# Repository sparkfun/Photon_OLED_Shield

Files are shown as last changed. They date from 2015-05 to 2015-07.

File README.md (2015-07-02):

SparkFun Photon OLED Shield
========================================

SparkFun Photon OLED Shield

[*SparkFun Photon OLED Shield (DEV-13628)*](https://www.sparkfun.com/products/13628)

The [SparkFun Photon OLED Shield](https://www.sparkfun.com/products/13231) breaks out a small monochrome, blue-on-black OLED to use with your Photon module. It’s “micro”, but it still packs a punch – the OLED display is crisp, and you can fit a deceivingly large amount of graphics on there. This shield is perfect for adding graphics to your Photon, displaying diagnostic information without resorting to serial output, and teaching a little game theory.

Repository Contents
-------------------

* **/Hardware** - Eagle design files (.brd, .sch)
* **/Production** - Production panel files (.brd)
* **/Libraries** - Firmware library and example code for the Particle Photon.

Documentation
--------------
* **[Hookup Guide](https://learn.sparkfun.com/tutorials/photon-oled-shield-hookup-guide)** - Hardware overview and example code.

Product Versions
----------------
* [DEV-13628](https://www.sparkfun.com/products/13628)- V1.0 release of the Photon OLED Shield.

License Information
-------------------
This product is _**open source**_! 

The **hardware** is released under [Creative Commons ShareAlike 4.0 International](https://creativecommons.org/licenses/by-sa/4.0/).

The **code**  license can be found in the source directory.

Please use, reuse, and modify these files as you see fit. Please maintain attribution to SparkFun Electronics and release anything derivative under the same license.

Distributed as-is; no warranty is given.

- Your friends at SparkFun.

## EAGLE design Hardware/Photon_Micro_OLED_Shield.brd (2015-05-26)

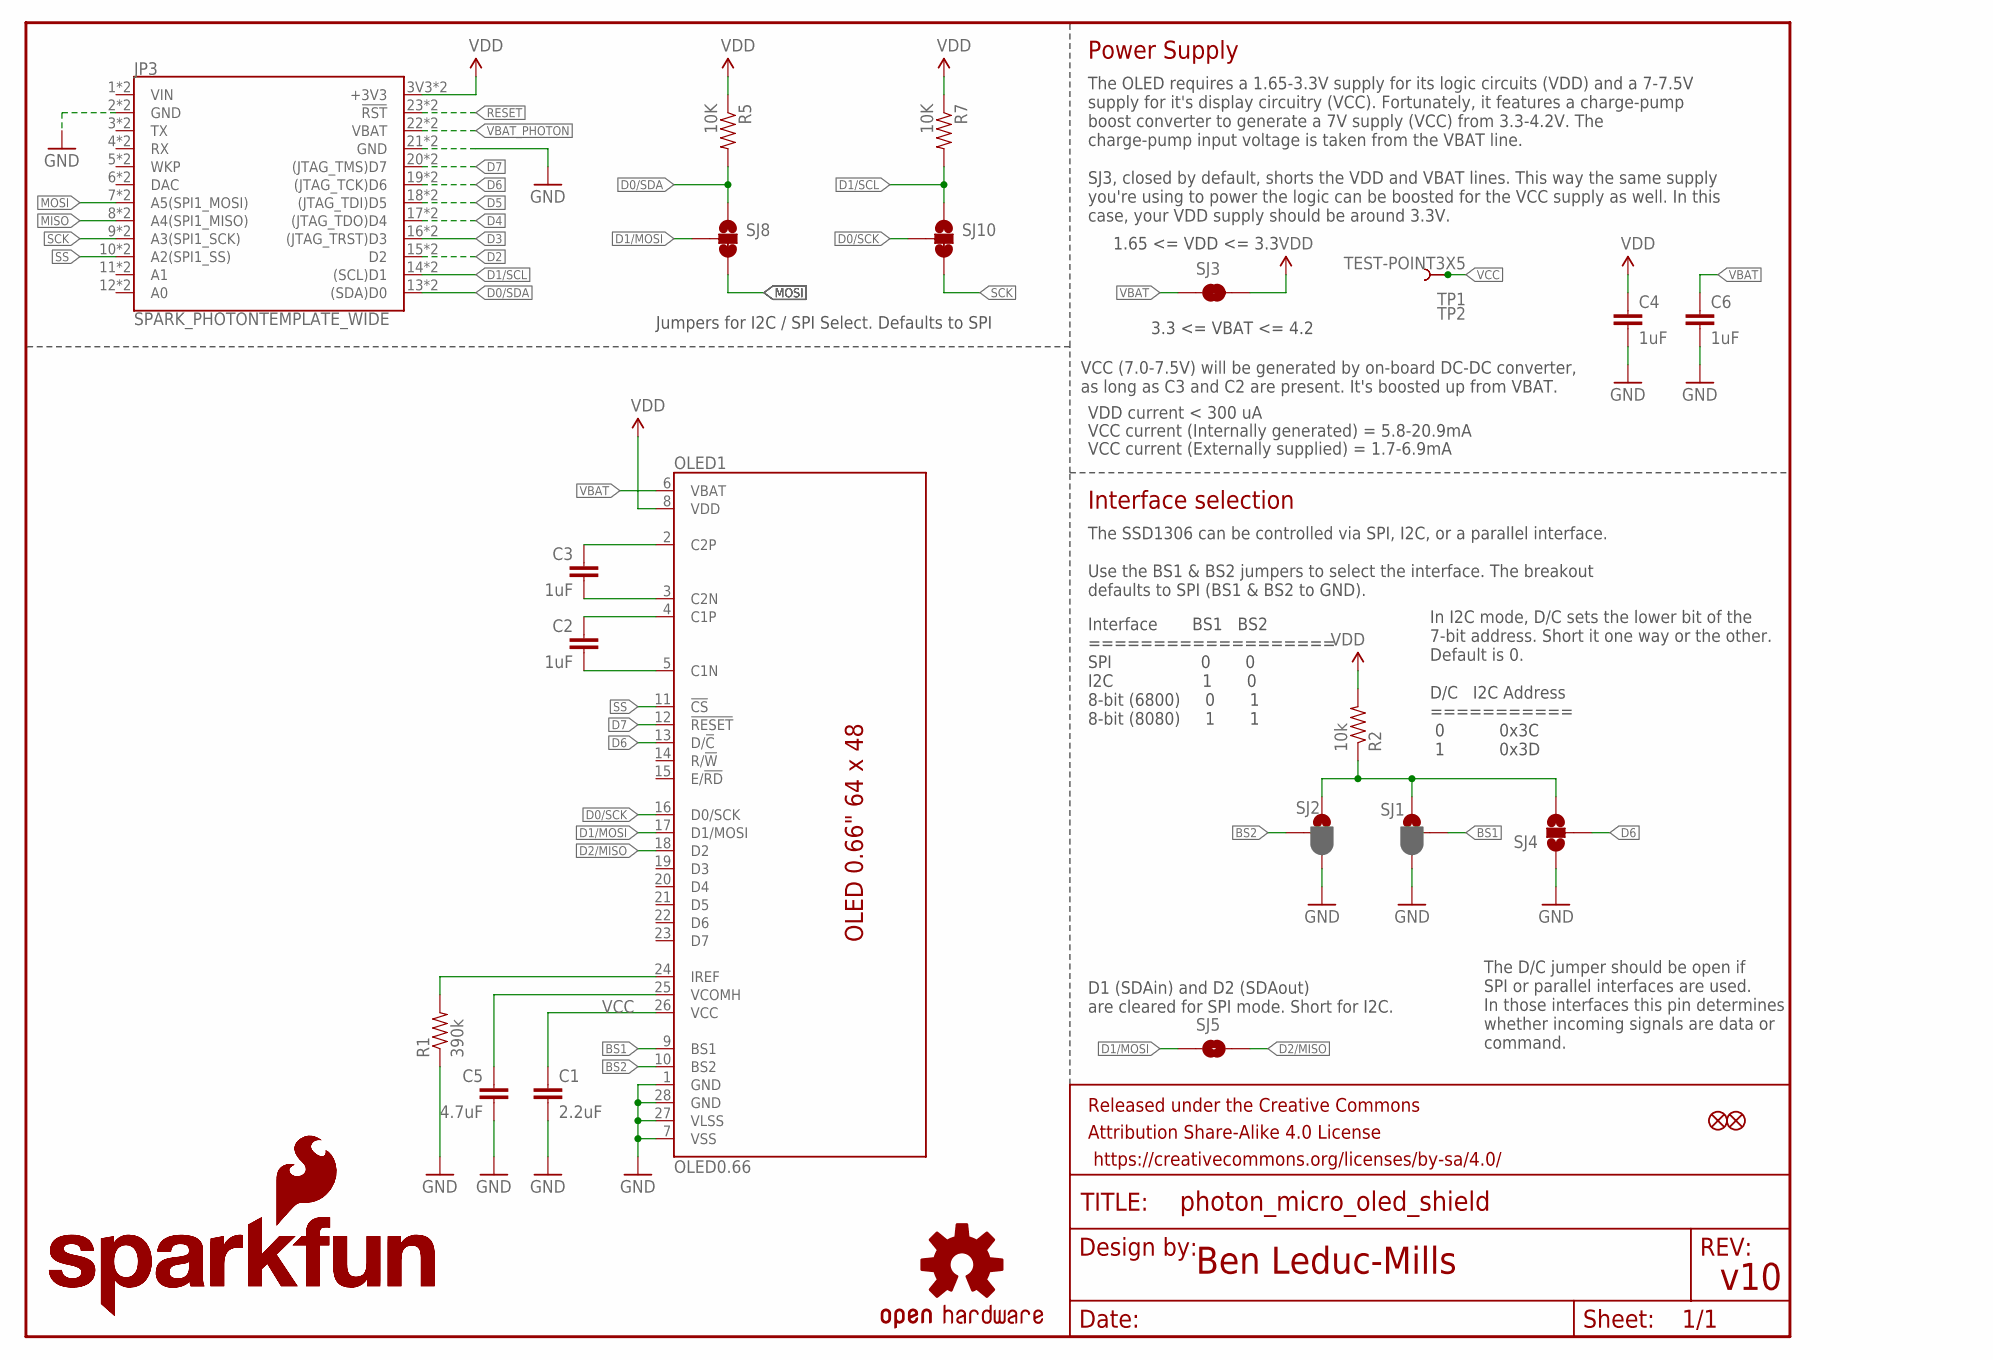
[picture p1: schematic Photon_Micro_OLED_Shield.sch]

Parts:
C1: 2.2uF; 0805-CAP
C2, C3: 1uF; 0805-CAP
C4, C6: 1uF; 0603-CAP
C5: 4.7uF; 1206-CAP
FID1, FID2: FIDUCIAL1X2; FIDUCIAL-1X2
FRAME1: FRAME-LETTER; CREATIVE_COMMONS
JP3: SPARK_PHOTONTEMPLATE_WIDE; SPARK_PHOTON_TEMPLATE_WIDE
LOGO1, LOGO2: SFE_LOGO_NAME_FLAME.1_INCH; SFE_LOGO_NAME_FLAME_.1
LOGO3: OSHW-LOGOS; OSHW-LOGO-S
OLED1: OLED0.66; OLED-0.66-64X48
R1: 390k; 0603-RES
R2: 10k; 0603-RES
R5, R7: 10K; 0603-RES
SJ1: BS1; PAD-JUMPER-3-2OF3_NC_BY_PASTE_YES_SILK_FULL_BOX
SJ2: BS2; PAD-JUMPER-3-2OF3_NC_BY_PASTE_YES_SILK_FULL_BOX
SJ3: JUMPER-PAD-2-NC_BY_TRACE; PAD-JUMPER-2-NC_BY_TRACE_YES_SILK
SJ4: JUMPER-PAD-3-NOYES_SILK; PAD-JUMPER-3-NO_YES_SILK
SJ5: JUMPER-PAD-2-NOYES_SILK; PAD-JUMPER-2-NO_YES_SILK
SJ8, SJ10: JUMPER-PAD-3-2OF3_NC_BY_TRACE_SMALL; PAD-JUMPER-3-2OF3_NC_BY_TRACE_YES_SILK_FULL_BOX
TP1, TP2: TEST-POINT3X5; PAD.03X.05

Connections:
BS1: OLED1.9 (BS1), SJ1.2
BS2: OLED1.10 (BS2), SJ2.2
C1N: C2.2, OLED1.5 (C1N)
C1P: C2.1, OLED1.4 (C1P)
C2N: C3.2, OLED1.3 (C2N)
C2P: C3.1, OLED1.2 (C2P)
D0/SCK: OLED1.16 (D0/SCK), SJ10.2
D0/SDA: JP3.13 ((SDA)D0), JP3.D0 ((SDA)D0), R5.2, SJ8.1
D1/MOSI: OLED1.17 (D1/MOSI), SJ5.1, SJ8.2
D1/SCL: JP3.14 ((SCL)D1), JP3.D1 ((SCL)D1), R7.2, SJ10.1
D2: JP3.15 (D2), JP3.D2
D2/MISO: OLED1.18 (D2), SJ5.2
D3: JP3.16 ((JTAG_TRST)D3), JP3.D3 ((JTAG_TRST)D3)
D4: JP3.17 ((JTAG_TDO)D4), JP3.D4 ((JTAG_TDO)D4)
D5: JP3.18 ((JTAG_TDI)D5), JP3.D5 ((JTAG_TDI)D5)
D6: JP3.19 ((JTAG_TCK)D6), JP3.D6 ((JTAG_TCK)D6), OLED1.13 (D/!C!), SJ4.2
D7: JP3.20 ((JTAG_TMS)D7), JP3.D7 ((JTAG_TMS)D7), OLED1.12 (!RESET!)
GND: C1.2, C4.2, C5.2, C6.2, JP3.2 (GND), JP3.21 (GND), JP3.GND@0 (GND), JP3.GND@2 (GND), OLED1.1 (GND), OLED1.7 (VSS), OLED1.27 (VLSS), OLED1.28 (GND), R1.1, SJ1.3, SJ2.3, SJ4.1
IREF: OLED1.24 (IREF), R1.2
MISO: JP3.8 (A4(SPI1_MISO)), JP3.A4 (A4(SPI1_MISO))
MOSI: JP3.7 (A5(SPI1_MOSI)), JP3.A5 (A5(SPI1_MOSI)), SJ8.3
RESET: JP3.23 (!RST!), JP3.RST (!RST!)
SCK: JP3.9 (A3(SPI1_SCK)), JP3.A3 (A3(SPI1_SCK)), SJ10.3
SS: JP3.10 (A2(SPI1_SS)), JP3.A2 (A2(SPI1_SS)), OLED1.11 (!CS!)
VBAT: C6.1, OLED1.6 (VBAT), SJ3.1
VBAT_PHOTON: JP3.22 (VBAT), JP3.VBAT
VCC: C1.1, OLED1.26 (VCC), TP1.P$1, TP2.P$1
VCOMH: C5.1, OLED1.25 (VCOMH)
VDD: C4.1, JP3.3V3 (+3V3), JP3.24 (+3V3), OLED1.8 (VDD), R2.2, R5.1, R7.1, SJ3.2
VDD_PU: R2.1, SJ1.1, SJ2.1, SJ4.3

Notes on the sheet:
v10
Ben Leduc-Mills
1.65 <= VDD <= 3.3
VDD current < 300 uA
VCC current (Internally generated) = 5.8-20.9mA
VCC current (Externally supplied) = 1.7-6.9mA
Interface BS1 BS2 =================== SPI 0 0 I2C 1 0 8-bit (6800) 0 1 8-bit (8080) 1 1
VCC (7.0-7.5V) will be generated by on-board DC-DC converter, as long as C3 and C2 are present. It's boosted up from VBAT.
3.3 <= VBAT <= 4.2
Interface selection
D1 (SDAin) and D2 (SDAout) are cleared for SPI mode. Short for I2C.
The SSD1306 can be controlled via SPI, I2C, or a parallel interface. Use the BS1 & BS2 jumpers to select the interface. The breakout defaults to SPI (BS1 & BS2 to GND).
In I2C mode, D/C sets the lower bit of the 7-bit address. Short it one way or the other. Default is 0. D/C I2C Address =========== 0 0x3C 1 0x3D
Power Supply
The OLED requires a 1.65-3.3V supply for its logic circuits (VDD) and a 7-7.5V supply for it's display circuitry (VCC). Fortunately, it features a charge-pump boost converter to generate a 7V supply (VCC) from 3.3-4.2V. The charge-pump input voltage is taken from the VBAT line. SJ3, closed by defau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
The D/C jumper should be open if SPI or parallel interfaces are used. In those interfaces this pin determines whether incoming signals are data or command.
Jumpers for I2C / SPI Select. Defaults to SPI

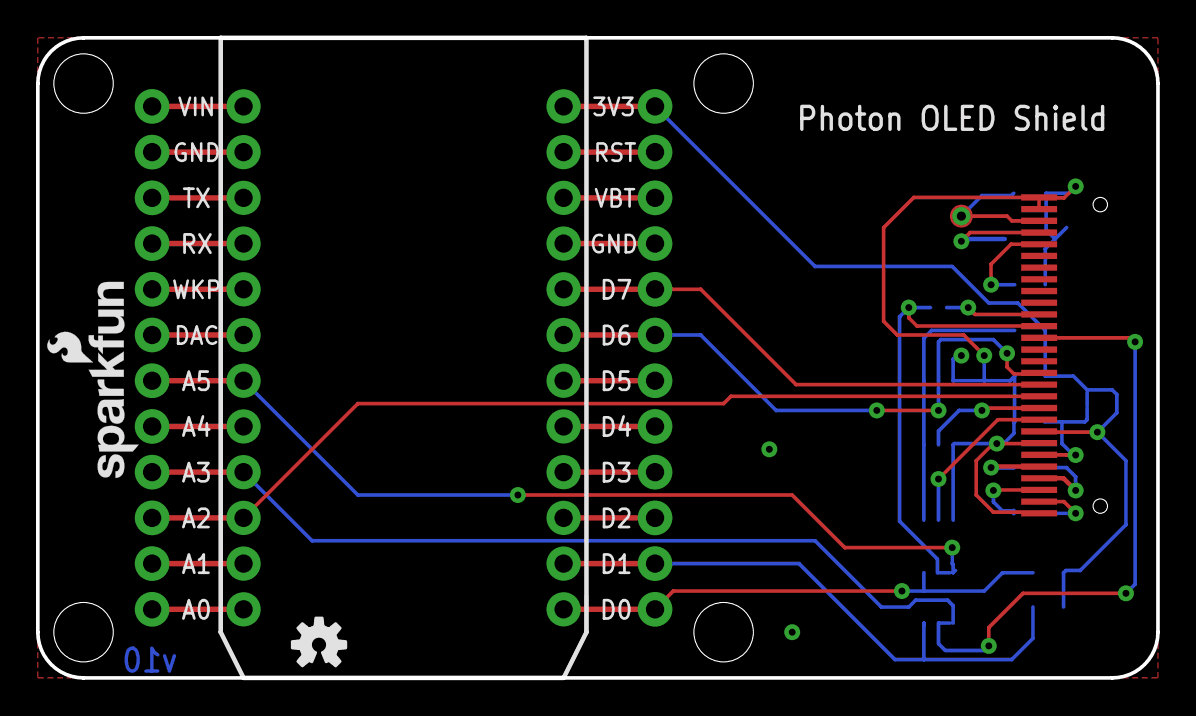
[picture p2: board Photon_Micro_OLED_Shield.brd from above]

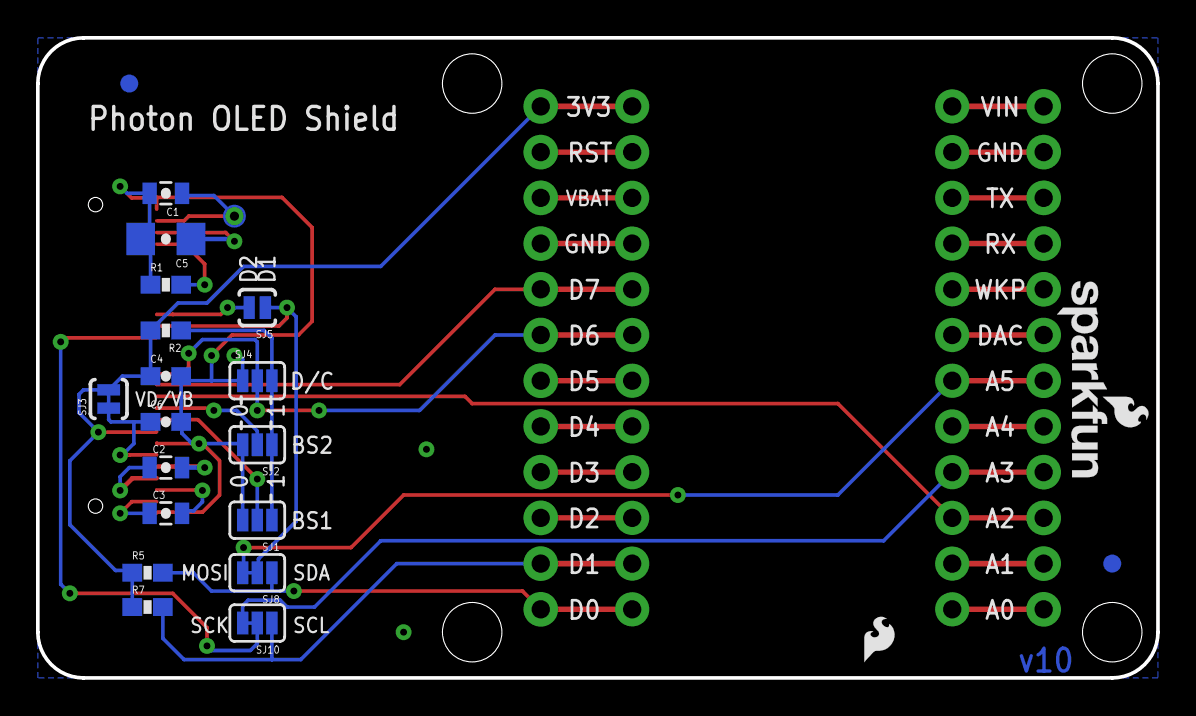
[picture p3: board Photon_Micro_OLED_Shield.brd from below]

Board: 2 copper layers, 62.2 x 35.6 mm, 28 parts (22 on the bottom side), 30 nets.

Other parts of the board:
U$1: SFE_LOGO_FLAME_.1

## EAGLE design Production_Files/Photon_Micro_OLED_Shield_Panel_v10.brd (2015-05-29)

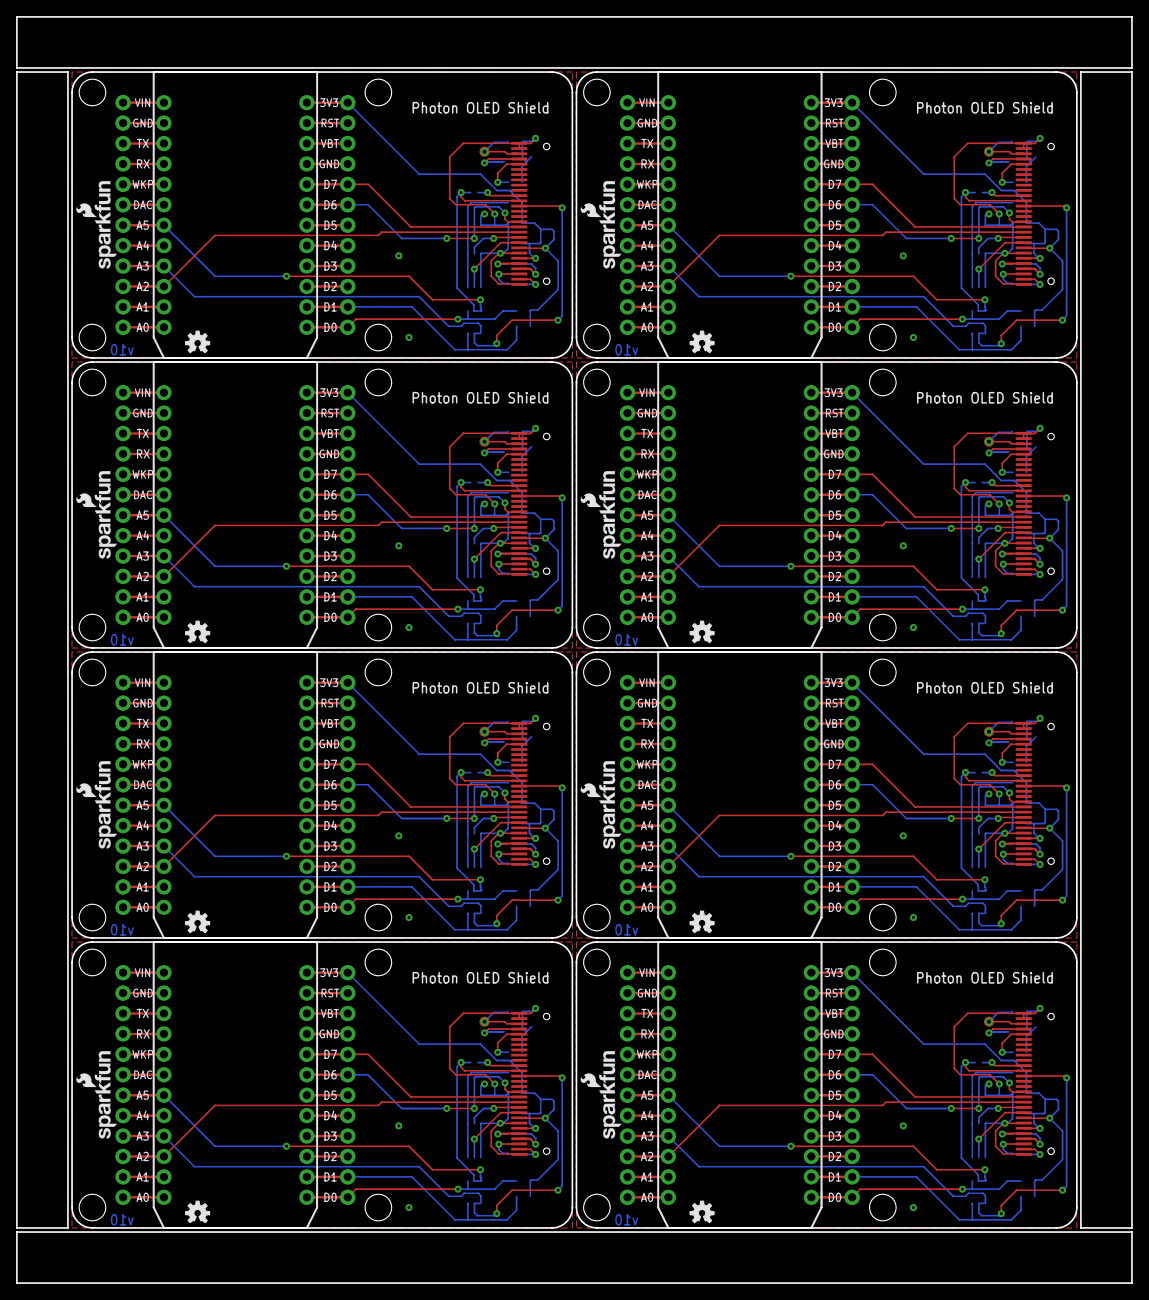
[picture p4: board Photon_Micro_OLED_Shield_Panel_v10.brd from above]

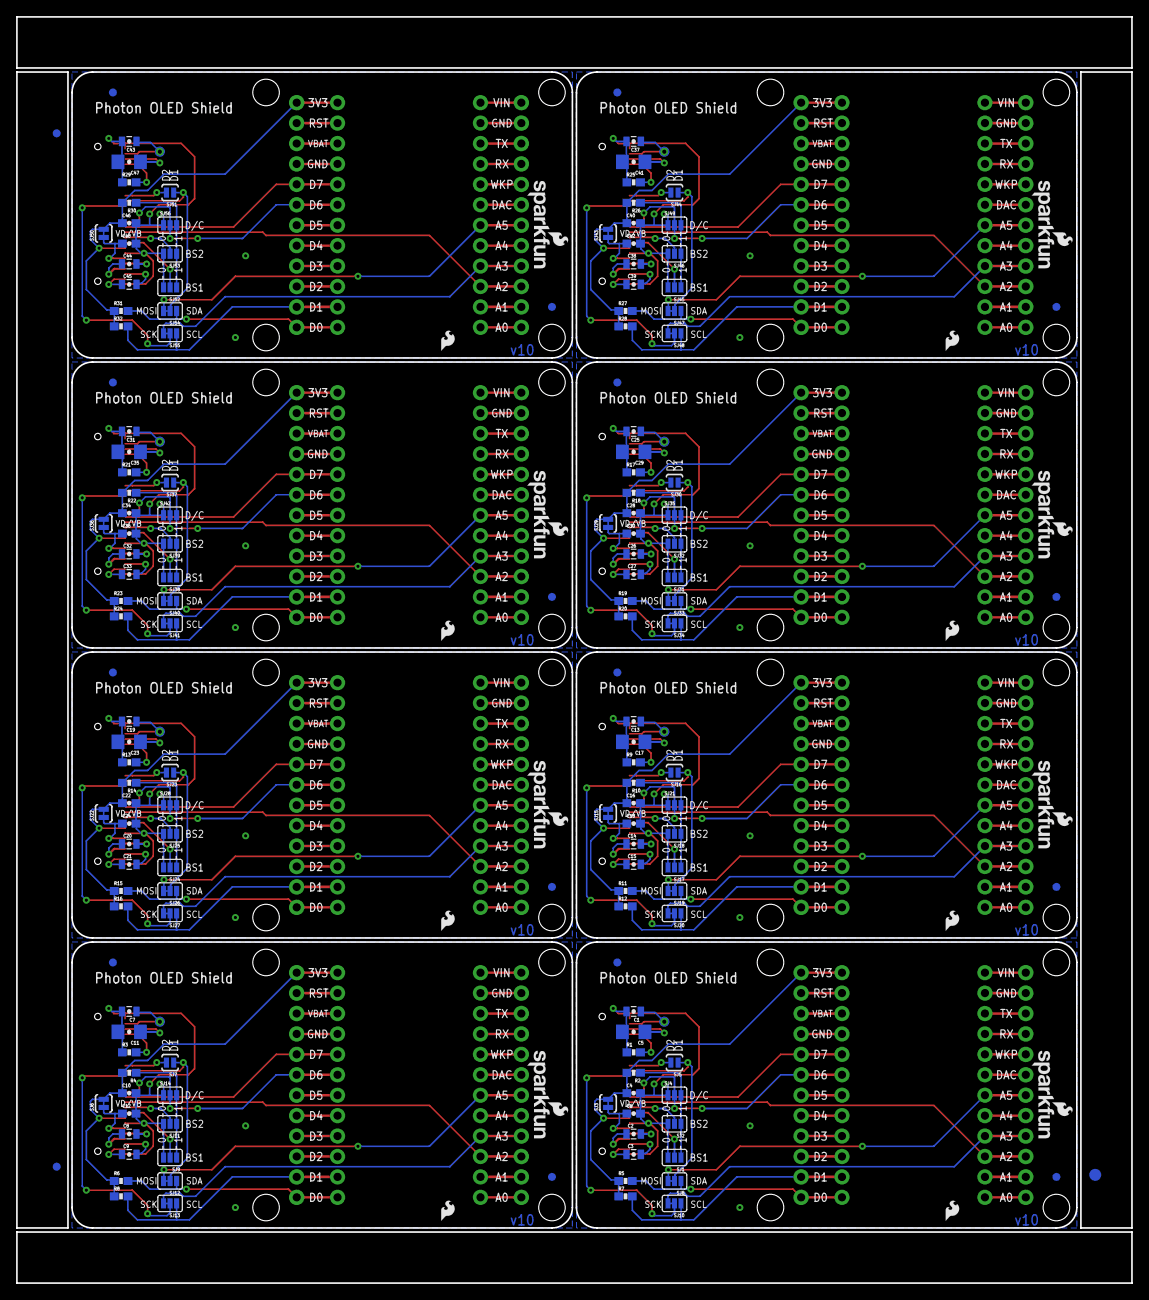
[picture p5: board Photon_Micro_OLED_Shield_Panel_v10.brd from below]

Board: 2 copper layers, 138.7 x 157.5 mm, 219 parts (179 on the bottom side), 240 nets.

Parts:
C1, C7, C13, C19, C25, C31, C37, C43: 2.2uF; 0805-CAP
C2, C3, C8, C9, C14, C15, C20, C21, C26, C27, C32, C33, C38, C39, C44, C45: 1uF; 0805-CAP
C4, C6, C10, C12, C16, C18, C22, C24, C28, C30, C34, C36, C40, C42, C46, C48: 1uF; 0603-CAP
C5, C11, C17, C23, C29, C35, C41, C47: 4.7uF; 1206-CAP
E$1: FIDUCIAL-1.5X3
E$4, E$5: FIDUCIAL-1X2
FID1, FID2, FID3, FID4, FID5, FID6, FID7, FID8, FID9, FID10, FID11, FID12, FID13, FID14, FID15, FID16: FIDUCIAL1X2; FIDUCIAL-1X2
JP1, JP2, JP3, JP4, JP5, JP6, JP7, JP8: SPARK_PHOTONTEMPLATE_WIDE; SPARK_PHOTON_TEMPLATE_WIDE
LOGO1, LOGO2, LOGO5, LOGO6, LOGO8, LOGO9, LOGO11, LOGO12, LOGO14, LOGO15, LOGO17, LOGO18, LOGO20, LOGO21, LOGO23, LOGO24: SFE_LOGO_NAME_FLAME.1_INCH; SFE_LOGO_NAME_FLAME_.1
LOGO3, LOGO4, LOGO7, LOGO10, LOGO13, LOGO16, LOGO19, LOGO22: OSHW-LOGOS; OSHW-LOGO-S
OLED1, OLED2, OLED3, OLED4, OLED5, OLED6, OLED7, OLED8: OLED0.66; OLED-0.66-64X48
R1, R3, R9, R13, R17, R21, R25, R29: 390k; 0603-RES
R2, R4, R10, R14, R18, R22, R26, R30: 10k; 0603-RES
R5, R6, R7, R8, R11, R12, R15, R16, R19, R20, R23, R24, R27, R28, R31, R32: 10K; 0603-RES
SJ1, SJ9, SJ17, SJ24, SJ31, SJ38, SJ45, SJ52: BS1; PAD-JUMPER-3-2OF3_NC_BY_PASTE_YES_SILK_FULL_BOX
SJ2, SJ11, SJ18, SJ25, SJ32, SJ39, SJ46, SJ53: BS2; PAD-JUMPER-3-2OF3_NC_BY_PASTE_YES_SILK_FULL_BOX
SJ3, SJ6, SJ15, SJ22, SJ29, SJ36, SJ43, SJ50: PAD-JUMPER-2-NC_BY_TRACE_YES_SILK
SJ4, SJ14, SJ21, SJ28, SJ35, SJ42, SJ49, SJ56: PAD-JUMPER-3-NO_YES_SILK
SJ5, SJ7, SJ16, SJ23, SJ30, SJ37, SJ44, SJ51: PAD-JUMPER-2-NO_YES_SILK
SJ8, SJ10, SJ12, SJ13, SJ19, SJ20, SJ26, SJ27, SJ33, SJ34, SJ40, SJ41, SJ47, SJ48, SJ54, SJ55: PAD-JUMPER-3-2OF3_NC_BY_TRACE_YES_SILK_FULL_BOX
TP1, TP2, TP3, TP4, TP5, TP6, TP7, TP8, TP9, TP10, TP11, TP12, TP13, TP14, TP15, TP16: TEST-POINT3X5; PAD.03X.05
U$1, U$2, U$3, U$4, U$5, U$6, U$7, U$8: SFE_LOGO_FLAME_.1

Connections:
BS1: OLED1.9, SJ1.2
BS2: OLED1.10, SJ2.2
BS3: OLED2.9, SJ9.2
BS4: OLED2.10, SJ11.2
BS5: OLED3.9, SJ17.2
BS6: OLED3.10, SJ18.2
BS7: OLED4.9, SJ24.2
BS8: OLED4.10, SJ25.2
BS9: OLED5.9, SJ31.2
BS10: OLED5.10, SJ32.2
BS11: OLED6.9, SJ38.2
BS12: OLED6.10, SJ39.2
BS13: OLED7.9, SJ45.2
BS14: OLED7.10, SJ46.2
BS15: OLED8.9, SJ52.2
BS16: OLED8.10, SJ53.2
C1N: C2.2, OLED1.5
C1N1: C8.2, OLED2.5
C1N2: C14.2, OLED3.5
C1N3: C20.2, OLED4.5
C1N4: C26.2, OLED5.5
C1N5: C32.2, OLED6.5
C1N6: C38.2, OLED7.5
C1N7: C44.2, OLED8.5
C1P: C2.1, OLED1.4
C1P1: C8.1, OLED2.4
C1P2: C14.1, OLED3.4
C1P3: C20.1, OLED4.4
C1P4: C26.1, OLED5.4
C1P5: C32.1, OLED6.4
C1P6: C38.1, OLED7.4
C1P7: C44.1, OLED8.4
C2N: C3.2, OLED1.3
C2N1: C9.2, OLED2.3
C2N2: C15.2, OLED3.3
C2N3: C21.2, OLED4.3
C2N4: C27.2, OLED5.3
C2N5: C33.2, OLED6.3
C2N6: C39.2, OLED7.3
C2N7: C45.2, OLED8.3
C2P: C3.1, OLED1.2
C2P1: C9.1, OLED2.2
C2P2: C15.1, OLED3.2
C2P3: C21.1, OLED4.2
C2P4: C27.1, OLED5.2
C2P5: C33.1, OLED6.2
C2P6: C39.1, OLED7.2
C2P7: C45.1, OLED8.2
D0/SCK: OLED1.16, SJ10.2
D0/SCK1: OLED2.16, SJ13.2
D0/SCK2: OLED3.16, SJ20.2
D0/SCK3: OLED4.16, SJ27.2
D0/SCK4: OLED5.16, SJ34.2
D0/SCK5: OLED6.16, SJ41.2
D0/SCK6: OLED7.16, SJ48.2
D0/SCK7: OLED8.16, SJ55.2
D0/SDA: JP3.13, JP3.D0, R5.2, SJ8.1
D0/SDA1: JP1.13, JP1.D0, R6.2, SJ12.1
D0/SDA2: JP2.13, JP2.D0, R11.2, SJ19.1
D0/SDA3: JP4.13, JP4.D0, R15.2, SJ26.1
D0/SDA4: JP5.13, JP5.D0, R19.2, SJ33.1
D0/SDA5: JP6.13, JP6.D0, R23.2, SJ40.1
D0/SDA6: JP7.13, JP7.D0, R27.2, SJ47.1
D0/SDA7: JP8.13, JP8.D0, R31.2, SJ54.1
D1: JP1.20, JP1.D7, OLED2.12
D1/MOSI: OLED1.17, SJ5.1, SJ8.2
D1/MOSI1: OLED2.17, SJ7.1, SJ12.2
D1/MOSI2: OLED3.17, SJ16.1, SJ19.2
D1/MOSI3: OLED4.17, SJ23.1, SJ26.2
D1/MOSI4: OLED5.17, SJ30.1, SJ33.2
D1/MOSI5: OLED6.17, SJ37.1, SJ40.2
D1/MOSI6: OLED7.17, SJ44.1, SJ47.2
D1/MOSI7: OLED8.17, SJ51.1, SJ54.2
D1/SCL: JP3.14, JP3.D1, R7.2, SJ10.1
D1/SCL1: JP1.14, JP1.D1, R8.2, SJ13.1
D1/SCL2: JP2.14, JP2.D1, R12.2, SJ20.1
D1/SCL3: JP4.14, JP4.D1, R16.2, SJ27.1
D1/SCL4: JP5.14, JP5.D1, R20.2, SJ34.1
D1/SCL5: JP6.14, JP6.D1, R24.2, SJ41.1
D1/SCL6: JP7.14, JP7.D1, R28.2, SJ48.1
D1/SCL7: JP8.14, JP8.D1, R32.2, SJ55.1
D2: JP3.15, JP3.D2
D2/MISO: OLED1.18, SJ5.2
D2/MISO1: OLED2.18, SJ7.2
D2/MISO2: OLED3.18, SJ16.2
D2/MISO3: OLED4.18, SJ23.2
D2/MISO4: OLED5.18, SJ30.2
D2/MISO5: OLED6.18, SJ37.2
D2/MISO6: OLED7.18, SJ44.2
D2/MISO7: OLED8.18, SJ51.2
D3: JP3.16, JP3.D3
D4: JP3.17, JP3.D4
D5: JP3.18, JP3.D5
D6: JP3.19, JP3.D6, OLED1.13, SJ4.2
D7: JP3.20, JP3.D7, OLED1.12
D8: JP1.19, JP1.D6, OLED2.13, SJ14.2
D9: JP1.18, JP1.D5
D10: JP1.17, JP1.D4
D11: JP1.15, JP1.D2
D12: JP1.16, JP1.D3
D13: JP2.20, JP2.D7, OLED3.12
D14: JP2.19, JP2.D6, OLED3.13, SJ21.2
D15: JP2.18, JP2.D5
D16: JP2.17, JP2.D4
D17: JP2.15, JP2.D2
D18: JP2.16, JP2.D3
D19: JP4.20, JP4.D7, OLED4.12
D20: JP4.19, JP4.D6, OLED4.13, SJ28.2
D21: JP4.18, JP4.D5
D22: JP4.17, JP4.D4
D23: JP4.15, JP4.D2
D24: JP4.16, JP4.D3
D25: JP5.20, JP5.D7, OLED5.12
D26: JP5.19, JP5.D6, OLED5.13, SJ35.2
D27: JP5.18, JP5.D5
D28: JP5.17, JP5.D4
D29: JP5.15, JP5.D2
D30: JP5.16, JP5.D3
D31: JP6.20, JP6.D7, OLED6.12
D32: JP6.19, JP6.D6, OLED6.13, SJ42.2
D33: JP6.18, JP6.D5
D34: JP6.17, JP6.D4
D35: JP6.15, JP6.D2
D36: JP6.16, JP6.D3
D37: JP7.20, JP7.D7, OLED7.12
D38: JP7.19, JP7.D6, OLED7.13, SJ49.2
D39: JP7.18, JP7.D5
D40: JP7.17, JP7.D4
D41: JP7.15, JP7.D2
D42: JP7.16, JP7.D3
D43: JP8.20, JP8.D7, OLED8.12
D44: JP8.19, JP8.D6, OLED8.13, SJ56.2
D45: JP8.18, JP8.D5
D46: JP8.17, JP8.D4
D47: JP8.15, JP8.D2
D48: JP8.16, JP8.D3
GND: C1.2, C4.2, C5.2, C6.2, JP3.2, JP3.21, JP3.GND@0, JP3.GND@2, OLED1.1, OLED1.7, OLED1.27, OLED1.28, R1.1, SJ1.3, SJ2.3, SJ4.1
GND1: C7.2, C10.2, C11.2, C12.2, JP1.2, JP1.21, JP1.GND@0, JP1.GND@2, OLED2.1, OLED2.7, OLED2.27, OLED2.28, R3.1, SJ9.3, SJ11.3, SJ14.1
GND2: C13.2, C16.2, C17.2, C18.2, JP2.2, JP2.21, JP2.GND@0, JP2.GND@2, OLED3.1, OLED3.7, OLED3.27, OLED3.28, R9.1, SJ17.3, SJ18.3, SJ21.1
GND3: C19.2, C22.2, C23.2, C24.2, JP4.2, JP4.21, JP4.GND@0, JP4.GND@2, OLED4.1, OLED4.7, OLED4.27, OLED4.28, R13.1, SJ24.3, SJ25.3, SJ28.1
GND4: C25.2, C28.2, C29.2, C30.2, JP5.2, JP5.21, JP5.GND@0, JP5.GND@2, OLED5.1, OLED5.7, OLED5.27, OLED5.28, R17.1, SJ31.3, SJ32.3, SJ35.1
GND5: C31.2, C34.2, C35.2, C36.2, JP6.2, JP6.21, JP6.GND@0, JP6.GND@2, OLED6.1, OLED6.7, OLED6.27, OLED6.28, R21.1, SJ38.3, SJ39.3, SJ42.1
GND6: C37.2, C40.2, C41.2, C42.2, JP7.2, JP7.21, JP7.GND@0, JP7.GND@2, OLED7.1, OLED7.7, OLED7.27, OLED7.28, R25.1, SJ45.3, SJ46.3, SJ49.1
GND7: C43.2, C46.2, C47.2, C48.2, JP8.2, JP8.21, JP8.GND@0, JP8.GND@2, OLED8.1, OLED8.7, OLED8.27, OLED8.28, R29.1, SJ52.3, SJ53.3, SJ56.1
IREF: OLED1.24, R1.2
IREF1: OLED2.24, R3.2
IREF2: OLED3.24, R9.2
IREF3: OLED4.24, R13.2
IREF4: OLED5.24, R17.2
IREF5: OLED6.24, R21.2
IREF6: OLED7.24, R25.2
IREF7: OLED8.24, R29.2
MISO: JP3.8, JP3.A4
MISO1: JP1.8, JP1.A4
MISO2: JP2.8, JP2.A4
MISO3: JP4.8, JP4.A4
MISO4: JP5.8, JP5.A4
MISO5: JP6.8, JP6.A4
MISO6: JP7.8, JP7.A4
MISO7: JP8.8, JP8.A4
MOSI: JP3.7, JP3.A5, SJ8.3
MOSI1: JP1.7, JP1.A5, SJ12.3
MOSI2: JP2.7, JP2.A5, SJ19.3
MOSI3: JP4.7, JP4.A5, SJ26.3
MOSI4: JP5.7, JP5.A5, SJ33.3
MOSI5: JP6.7, JP6.A5, SJ40.3
MOSI6: JP7.7, JP7.A5, SJ47.3
MOSI7: JP8.7, JP8.A5, SJ54.3
RESET: JP3.23, JP3.RST
RESET1: JP1.23, JP1.RST
RESET2: JP2.23, JP2.RST
RESET3: JP4.23, JP4.RST
RESET4: JP5.23, JP5.RST
RESET5: JP6.23, JP6.RST
RESET6: JP7.23, JP7.RST
RESET7: JP8.23, JP8.RST
SCK: JP3.9, JP3.A3, SJ10.3
SCK1: JP1.9, JP1.A3, SJ13.3
SCK2: JP2.9, JP2.A3, SJ20.3
SCK3: JP4.9, JP4.A3, SJ27.3
SCK4: JP5.9, JP5.A3, SJ34.3
SCK5: JP6.9, JP6.A3, SJ41.3
SCK6: JP7.9, JP7.A3, SJ48.3
SCK7: JP8.9, JP8.A3, SJ55.3
SS: JP3.10, JP3.A2, OLED1.11
SS1: JP1.10, JP1.A2, OLED2.11
SS2: JP2.10, JP2.A2, OLED3.11
SS3: JP4.10, JP4.A2, OLED4.11
SS4: JP5.10, JP5.A2, OLED5.11
SS5: JP6.10, JP6.A2, OLED6.11
SS6: JP7.10, JP7.A2, OLED7.11
SS7: JP8.10, JP8.A2, OLED8.11
VBAT: C6.1, OLED1.6, SJ3.1
VBAT1: C12.1, OLED2.6, SJ6.1
VBAT2: C18.1, OLED3.6, SJ15.1
VBAT3: C24.1, OLED4.6, SJ22.1
VBAT4: C30.1, OLED5.6, SJ29.1
VBAT5: C36.1, OLED6.6, SJ36.1
VBAT6: C42.1, OLED7.6, SJ43.1
VBAT7: C48.1, OLED8.6, SJ50.1
VBAT_PHOTON: JP3.22, JP3.VBAT
VBAT_PHOTON1: JP1.22, JP1.VBAT
VBAT_PHOTON2: JP2.22, JP2.VBAT
VBAT_PHOTON3: JP4.22, JP4.VBAT
VBAT_PHOTON4: JP5.22, JP5.VBAT
VBAT_PHOTON5: JP6.22, JP6.VBAT
VBAT_PHOTON6: JP7.22, JP7.VBAT
VBAT_PHOTON7: JP8.22, JP8.VBAT
VCC: C1.1, OLED1.26, TP1.P$1, TP2.P$1
VCC1: C7.1, OLED2.26, TP3.P$1, TP4.P$1
VCC2: C13.1, OLED3.26, TP5.P$1, TP6.P$1
VCC3: C19.1, OLED4.26, TP7.P$1, TP8.P$1
VCC4: C25.1, OLED5.26, TP9.P$1, TP10.P$1
VCC5: C31.1, OLED6.26, TP11.P$1, TP12.P$1
VCC6: C37.1, OLED7.26, TP13.P$1, TP14.P$1
VCC7: C43.1, OLED8.26, TP15.P$1, TP16.P$1
VCOMH: C5.1, OLED1.25
VCOMH1: C11.1, OLED2.25
VCOMH2: C17.1, OLED3.25
VCOMH3: C23.1, OLED4.25
VCOMH4: C29.1, OLED5.25
VCOMH5: C35.1, OLED6.25
VCOMH6: C41.1, OLED7.25
VCOMH7: C47.1, OLED8.25
VDD: C4.1, JP3.3V3, JP3.24, OLED1.8, R2.2, R5.1, R7.1, SJ3.2
VDD1: C10.1, JP1.3V3, JP1.24, OLED2.8, R4.2, R6.1, R8.1, SJ6.2
VDD2: C16.1, JP2.3V3, JP2.24, OLED3.8, R10.2, R11.1, R12.1, SJ15.2
VDD3: C22.1, JP4.3V3, JP4.24, OLED4.8, R14.2, R15.1, R16.1, SJ22.2
VDD4: C28.1, JP5.3V3, JP5.24, OLED5.8, R18.2, R19.1, R20.1, SJ29.2
VDD5: C34.1, JP6.3V3, JP6.24, OLED6.8, R22.2, R23.1, R24.1, SJ36.2
VDD6: C40.1, JP7.3V3, JP7.24, OLED7.8, R26.2, R27.1, R28.1, SJ43.2
VDD7: C46.1, JP8.3V3, JP8.24, OLED8.8, R30.2, R31.1, R32.1, SJ50.2
VDD_PU: R2.1, SJ1.1, SJ2.1, SJ4.3
VDD_PU1: R4.1, SJ9.1, SJ11.1, SJ14.3
VDD_PU2: R10.1, SJ17.1, SJ18.1, SJ21.3
VDD_PU3: R14.1, SJ24.1, SJ25.1, SJ28.3
VDD_PU4: R18.1, SJ31.1, SJ32.1, SJ35.3
VDD_PU5: R22.1, SJ38.1, SJ39.1, SJ42.3
VDD_PU6: R26.1, SJ45.1, SJ46.1, SJ49.3
VDD_PU7: R30.1, SJ52.1, SJ53.1, SJ56.3

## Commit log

2015-03-19 Hardware
    First commit
    [Photon_Micro_OLED_Shield.brd, Photon_Micro_OLED_Shield.sch]
2015-03-25 qc fixes
    [Photon_Micro_OLED_Shield.brd, Photon_Micro_OLED_Shield.sch]
2015-04-01 new design
    moved screen to top and extended board so it will work better with the
    rest of the photon shields
    [Photon_Micro_OLED_Shield.brd, Photon_Micro_OLED_Shield.sch]
2015-05-11 Adding gap between Photon and pin-break outs. Moving D/C to pin D6.
    [Photon_Micro_OLED_Shield.brd, Photon_Micro_OLED_Shield.sch]
2015-05-11 Reorganizing file structure to match standard.
    [Photon_Micro_OLED_Shield.brd, Photon_Micro_OLED_Shield.sch]
2015-05-11 Changes per design review (right place)
    Board width fixed to allow space for headers and OLED screen.
    [Photon_Micro_OLED_Shield.brd]
2015-05-11 changed board name per new naming conventions
    [Photon_Micro_OLED_Shield.brd]
2015-05-22 Revising board name. Zero-ing origin, fixing measures.
    [Photon_Micro_OLED_Shield.brd]
2015-05-22 Updating silk. Bringing board edge in a bit.
    [Photon_Micro_OLED_Shield.brd, Photon_Micro_OLED_Shield.sch]
2015-05-26 Moved fiducially to bottom per issue #8
    [Photon_Micro_OLED_Shield.sch]
2015-05-26 issue fix
    [Photon_Micro_OLED_Shield.brd]
2015-05-29 created panel v10
    [Photon_Micro_OLED_Shield_Panel_v10.brd]
2015-09-03 Cleaned up the schematic a lot
    [Photon_Micro_OLED_Shield.sch]

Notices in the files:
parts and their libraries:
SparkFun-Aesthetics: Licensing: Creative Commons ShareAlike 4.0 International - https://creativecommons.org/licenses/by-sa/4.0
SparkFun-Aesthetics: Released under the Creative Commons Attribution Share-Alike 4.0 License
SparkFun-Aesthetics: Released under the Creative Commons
